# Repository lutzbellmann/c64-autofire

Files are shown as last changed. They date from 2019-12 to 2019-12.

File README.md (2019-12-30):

# c64-autofire
Autofire Adapter for the Commodore 64 Control Ports

# Features
Dual Port, configurable Autofire Adapter for the C64 with any digital Joystick

- No external power supply; powered by the Commodore 64
- Tap on/ Tap off function
- no potis, no switches, 1 button control
- configurable for 4 different autofire speeds; 10Hz, 3,8Hz, 1,9Hz, 1,2Hz
- highly stable autofire frequency, due to hardware timers
- Port A and Port B fully independent
- fire button overrides autofire (f.e. load weapon *KATAKIS*)
- port functions fully retained; mouse or other appliances can be used without restrictions
- autofire speed for each port is retained for next power-up (saved to eeprom)
- autofire off on computer power-up (no more glitches due to forgotten Autofire switch ;-) )

# Installation
Schematics can be found in the respective folder. I added the PCB layout from KiCAD as well as the GERBER data. I am not proficient at this, so the GERBER data ma not be good enough for PCB manufacturing. Please check for yourself. Maybe, somebody can help.
Parts list:
- PCB
- Attiny45
- 2x BZX85 Diodes 5,6V or higher
- 2x 15nF ceramic capacitors
- 2x female DB9 connector
- 2x male DB9 connector

Housing:
I have put some FreeCAD files and STLs in the respective folder. Use at will, or make your own.

Flashing the Attiny:
- compatible flash programmer needed (f.e. STK500, TL866, Arduino like programmes,....)
- WARNING: flashing the Attiny will only work once with ISP programmers, since the Fuses are written to disable the Reset pin (PB5).
  For future programming/ reuse a high voltage programmer is needed.
- to compile the *.asm file, install AVRA with "sudo apt install avra"
- to flash using an STK500 or similar programmer, install AVRDUDE: "sudo apt install avrdude"

There are in general two options for programming:
1) - Use the Makefile to produce your own binaries and flash
Fix your directories and programmer in the Makefile.
To flash the chip and write the fuses, connect your programmer incl. Attiny and run:
sudo make install

2) - Use the HEX binaries included
You can flash the chip without compiling the assembly to binary by using the *.hex file provided.
To use AVR Dude in the directory with the hex file:
sudo avrdude -p t45 -P (your interface) -c (your programmer) -B 1024 -U flash:w:C64_autofire.hex

Then you have to burn the fuses with:

sudo $(AVRDUDE) -p t45 -P (your interface) -c (your programmer) -B 1024 -U lfuse:w:0xe2:m -U hfuse:w:0x57:m

For "your interface" choose the interface your programmer is connected to. F.e. /dev/ttyACM0 or COM3.
See detailed instructions for using AVRDUDE under https://linux.die.net/man/1/avrdude.

WARNING: check your circuit properly! Connection errors and short circuits could destroy your C64! No warranty is given for any usage
of this Autofire adapter. Do not try it, if you are not knowing what you are doing. Usage at your own risk!

# Usage
Plug in the autofire adapter carfully into the C64 Control Ports and switch on the computer.

Configuration of autofire speed:
- hold down config button for the respective port and tap the joystick button 1-4 times depending on the autofire speed you want.
1x -> very slow ... 4x -> very fast; after 1 sec speed is saved for that port
- activate autofire for the respective port by tapping the config button once
- tap again for deactivation

HAVE FUN

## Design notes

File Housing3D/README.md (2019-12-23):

This folder contains all the files related to the housing.
These files currently are for the housing I have used for the prototype.
Can be sliced and 3D printed.

Use FreeCAD to work on the housing.

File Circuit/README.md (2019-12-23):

This folder contains the schematic of the circuit and all related files.
Use KiCAD to view and edit the schematic.

More to come:
- PCB layout
- Parts list

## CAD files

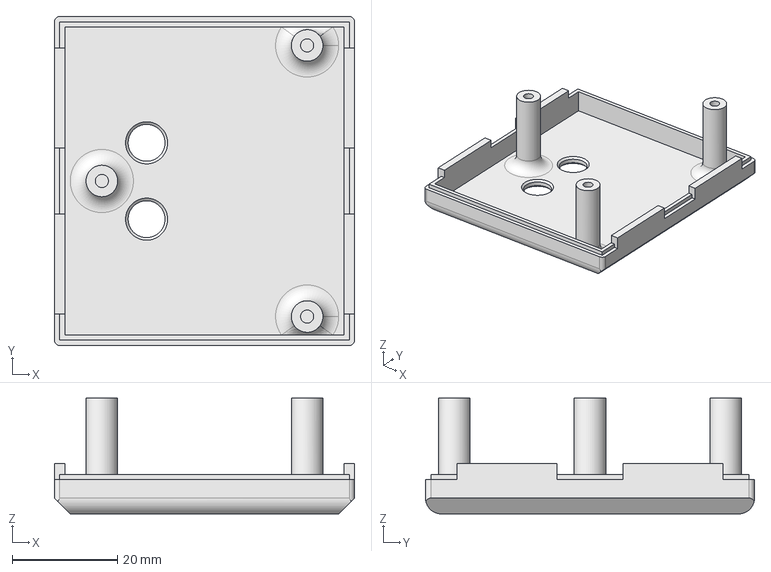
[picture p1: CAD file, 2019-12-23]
Housing3D/C64_autofire_top.FCStd
57.0 x 62.5 x 22.0 mm

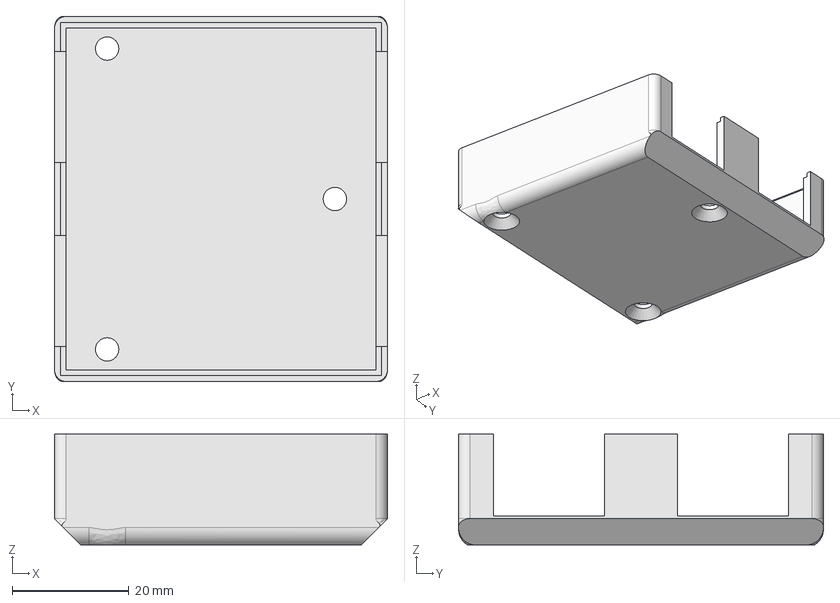
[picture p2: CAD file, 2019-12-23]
Housing3D/C64_autofire_bottom.FCStd
57.1 x 62.5 x 19.0 mm

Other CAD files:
C64_autofire.obj
Housing3D/C64_autofire_bottom.stl
Housing3D/C64_autofire_top.stl

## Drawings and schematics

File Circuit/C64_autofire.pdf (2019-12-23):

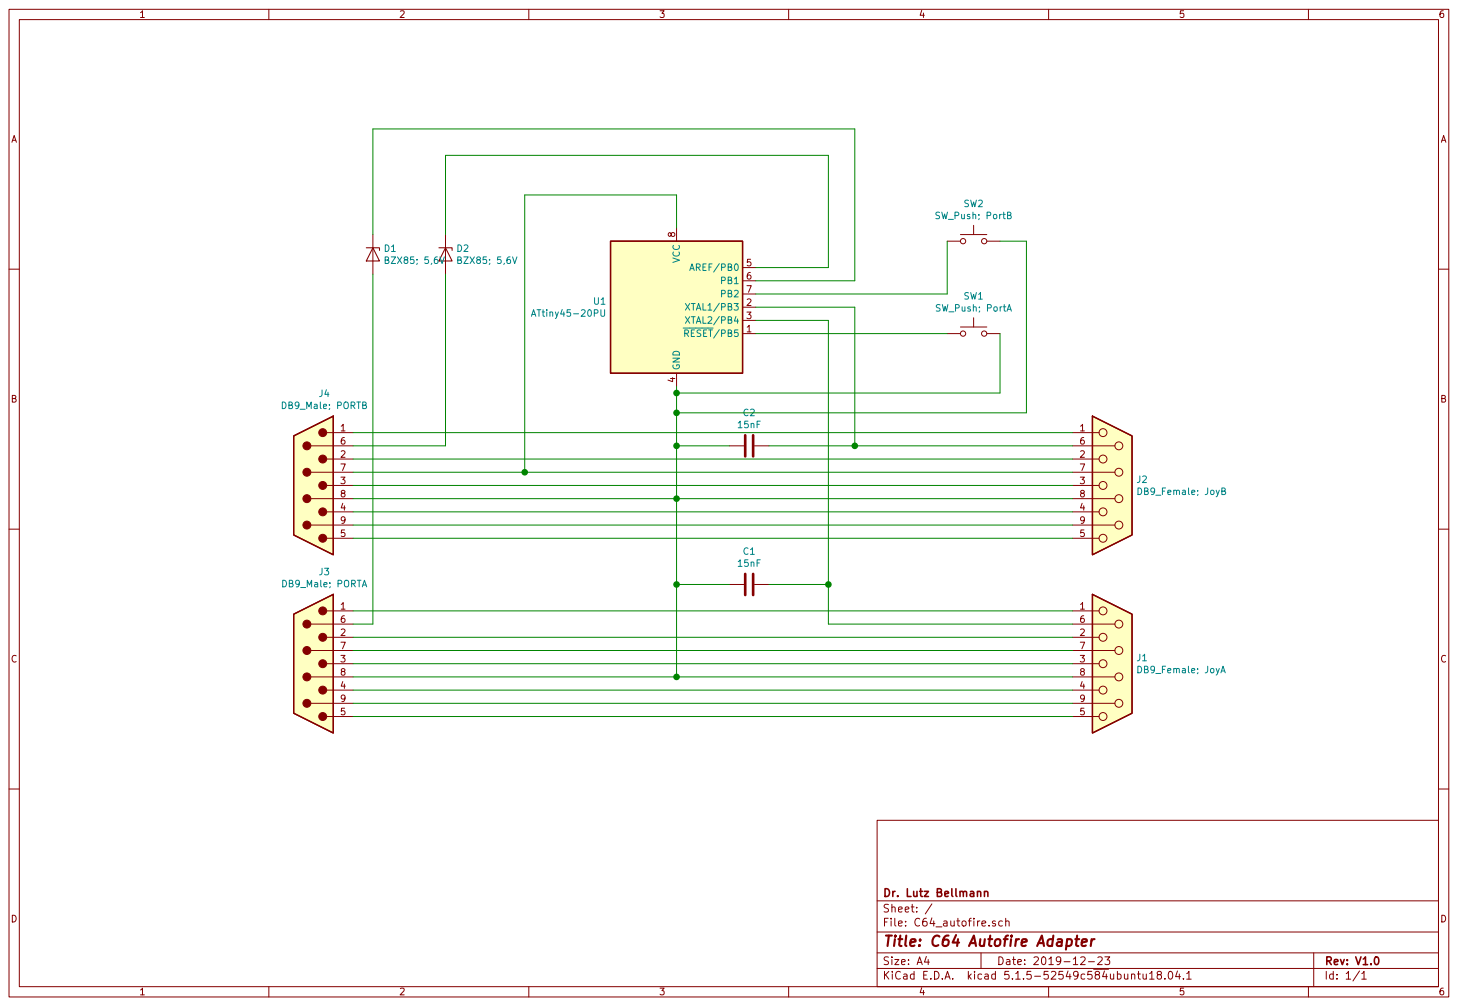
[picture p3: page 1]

File: C64_autofire.sch Sheet: / Dr. Lutz Bellmann

Id: 1/1 Title: C64 Autofire Adapter

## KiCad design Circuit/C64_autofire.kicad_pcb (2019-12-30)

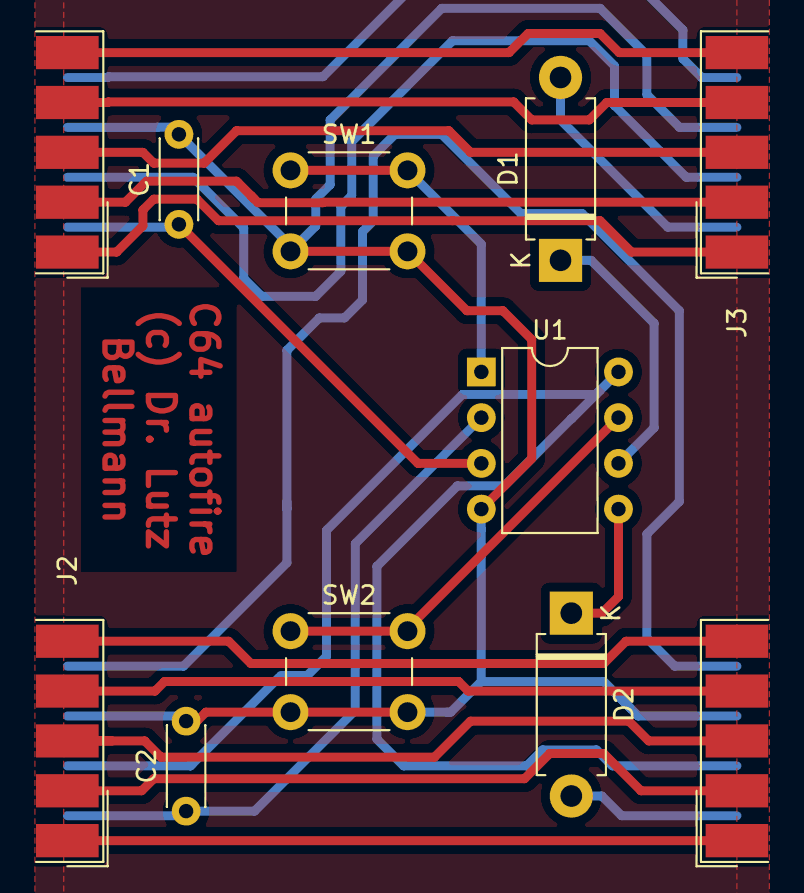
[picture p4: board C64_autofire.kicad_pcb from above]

Board: 2 copper layers, 11 parts (0 on the bottom side), 23 nets.

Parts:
C1, C2: 15nF; C_Disc_D4.3mm_W1.9mm_P5.00mm
D1, D2: BZX85; 5,6V; D_DO-15_P10.16mm_Horizontal
J1: DB9_Female; JoyA; DSUB-9_Female_EdgeMount_P2.77mm
J2: DB9_Female; JoyB; DSUB-9_Female_EdgeMount_P2.77mm
J3: DB9_Male; PORTA; DSUB-9_Male_EdgeMount_P2.77mm
J4: DB9_Male; PORTB; DSUB-9_Male_EdgeMount_P2.77mm
SW1: SW_Push; PortA; SW_PUSH_6mm_H9.5mm
SW2: SW_Push; PortB; SW_PUSH_6mm_H9.5mm
U1: ATtiny45-20PU; DIP-8_W7.62mm

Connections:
unnamed: C1.1, J1.6, U1.3
unnamed: C1.2, C2.2, J1.8, J2.8, J3.8, J4.8, SW1.2, SW2.2, U1.4
unnamed: C2.1, J2.6, U1.2
unnamed: D1.1, U1.6
unnamed: D1.2, J3.6
unnamed: D2.1, U1.5
unnamed: D2.2, J4.6
unnamed: J1.1, J3.1
unnamed: J1.2, J3.2
unnamed: J1.3, J3.3
unnamed: J1.4, J3.4
unnamed: J1.5, J3.5
unnamed: J1.7, J3.7
unnamed: J1.9, J3.9
unnamed: J2.1, J4.1
unnamed: J2.2, J4.2
unnamed: J2.3, J4.3
unnamed: J2.4, J4.4
unnamed: J2.5, J4.5
unnamed: J2.7, J4.7, U1.8
unnamed: J2.9, J4.9
unnamed: SW1.1, U1.1
unnamed: SW2.1, U1.7

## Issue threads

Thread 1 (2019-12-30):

Pre-compiled HEX

mamejay, 2019-12-30:
Hello there.  Great device.  I am wanting to make one and just wondered if the C64_autofire.hex is ready to go.
Also if this is ready to go, when I program using avrdude do I need to add any fuse settings?
I see lfuse:w:0xe2:m -U hfuse:w:0x57:m in the Makefile

Thanks

lutzbellmann, 2019-12-30:
Hi!
The HEX is ready to go. With sudo make install you will create a new one, flash AND set the fuses.
Be aware that all pins of the Attiny are used incl PB5. The fuses are set to RSTDISBL. You can‘t flash the device again with ISP afterwards, you need HV Serial programmer or new Attiny.

mamejay, 2019-12-30:
Excellent.  So I can program your HEX file using a command something like this?
**_avrdude -c arduino -P com3 -p t45 -b 19200 -U flash:w:C64_autofire.hex:i -B 1024 -U lfuse:w:0xe2:m -U hfuse:w:0x57:m_**

lutzbellmann, 2019-12-30:
this should work. Thanks for bringing this up.
Installation instructions should be updated for different programmers.

lutzbellmann, 2019-12-30:
Installation instructions will be handeled, when there is time

Closed 2019-12-30.

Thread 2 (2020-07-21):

Cannot get this to work

mamejay, 2020-07-21:
Hi There.  I have managed to build a unit up.  I have double and tripled checked your schematic and board against my board.
I programmed the attiny using a Uno and using the follow command in windows
avrdude -c arduino -P com3 -p t45 -b 19200 -U flash:w:C64_autofire.hex:i -B 1024 -U lfuse:w:0xe2:m -U hfuse:w:0x57:m

This successfully wrote no issues.
The only thing I can see I that could be wrong is that I am using BZV55 5.6V zener diode instead of the BZX85 one your mentioned.
I have checked the joystick button input on either side of the diode.  On the cathode side I am not getting any pulldown on the signal at all.
 I have checked the spec sheet but cannot determine what the main differences are.    Could this be the issue I am having?
Let me know if you have any advise.
Thanks

lutzbellmann, 2020-07-21:
Hi mamejay,
I checked the circuit myself again with my adapter and could not find any issue(schematics should be ok).
Type of Zdiode should not matter, if >=5.6V. This is only there as a precaution to avoid any current flow towards the C64 during switching of the port.
If you have programmed a successfully, you **should not** be able to program the Attiny again with a serial programmer, since the fuses disable the reset port.
So the hex must be written first, and then the fuses. With a new t45 do:
avrdude -c arduino -P com3 -p t45 -b 19200 -U flash:w:C64_autofire.hex:i -B 1024
avrdude -c arduino -P com3 -p t45 -b 19200 -B 1024 -U lfuse:w:0xe2:m -U hfuse:w:0x57:m
I am not sure what Arduino IDE is actually doing, so this could be a hint.

mamejay, 2020-07-22:
Thanks for that.  I tried programming another chip by splitting programming as you mentioned and doing the fuses after.
After flashing the hex the chip was not recognised so could not apply the fuses.
I did another using the single line for AVRdude but same issues where the button does nothing..  Here is the output from the command.
Anyway might just put this one in the too hard basket.  Thanks.

C:\Users\Jason\Google Drive\AVRDUDE>avrdude -c arduino -P com3 -p t45 -b 19200 -U flash:w:C64_autofire.hex:i -B 1024 -U lfuse:w:0xe2:m -U hfuse:w:0x57:m

avrdude: AVR device initialized and ready to accept instructions

Reading | ################################################## | 100% 0.04s

avrdude: Device signature = 0x1e9206 (probably t45)
avrdude: NOTE: "flash" memory has been specified, an erase cycle will be performed
         To disable this feature, specify the -D option.
avrdude: erasing chip
avrdude: reading input file "C64_autofire.hex"
avrdude: writing flash (580 bytes):

Writing | ################################################## | 100% 1.15s

avrdude: 580 bytes of flash written
avrdude: verifying flash memory against C64_autofire.hex:
avrdude: load data flash data from input file C64_autofire.hex:
avrdude: input file C64_autofire.hex contains 580 bytes
avrdude: reading on-chip flash data:

Reading | ################################################## | 100% 0.59s

avrdude: verifying ...
avrdude: 580 bytes of flash verified
avrdude: reading input file "0xe2"
avrdude: writing lfuse (1 bytes):

Writing | ################################################## | 100% 0.04s

avrdude: 1 bytes of lfuse written
avrdude: verifying lfuse memory against 0xe2:
avrdude: load data lfuse data from input file 0xe2:
avrdude: input file 0xe2 contains 1 bytes
avrdude: reading on-chip lfuse data:

Reading | ################################################## | 100% 0.02s

avrdude: verifying ...
avrdude: 1 bytes of lfuse verified
avrdude: reading input file "0x57"
avrdude: writing hfuse (1 bytes):

Writing | ################################################## | 100% 0.03s

avrdude: 1 bytes of hfuse written
avrdude: verifying hfuse memory against 0x57:
avrdude: load data hfuse data from input file 0x57:
avrdude: input file 0x57 contains 1 bytes
avrdude: reading on-chip hfuse data:

Reading | ################################################## | 100% 0.02s

avrdude: verifying ...
avrdude: 1 bytes of hfuse verified

avrdude: safemode: Fuses OK (E:FF, H:57, L:E2)

avrdude done.  Thank you.

lutzbellmann, 2020-07-25:
Sorry for the late reply. Don't give up yet.
Please try the following:
- Take the Attiny, where you couldn't write the fuses after writing the hex
- write the HEX again (not the fuses!), try a lower -B value in the AVRDUDE command line (Bitlock value)
- try until you can consistently write the hex on the chip (start with -B 512, -B 256 , ...)
- after that: write the fuses

Explanation:
For the autofire the clockspeed of the Attiny is adjusted to 31.25kHz. The Attiny can't keep up with the speed of the programmer, after you have written the hex with the standard Bitlock value of 1. Higher Bitlock values lower the frequency of certain programmers. 1024 worked for me, may be too much for your arduino programmer.

mamejay, 2020-07-25:
Thanks for that.  Just tried again with a fresh chip as the other one I have no idea were it went.
I get the same issue.  I can program the hex once and then chip is not recognised.   I try -B 512 -B 256 -B 128 -B 64 etc but same.
I will look at if there is limitations with the Uno.

mamejay, 2020-07-25:
Looks like Uno as a ISP is not ideal.
https://forum.arduino.cc/index.php?topic=71973.0
Looks like the -B switch does not work with a UNO.  Always handy to have another option.  I will see if I can grab one locally here in Australia which will be pretty much impossible

lutzbellmann, 2020-07-25:
oh greetings to the other side of the world from Germany! :-)
I am pretty sure you will be able to find a decent programmer. Get a TL866 II+ or compatible. The thing can do almost anything; even locks open your dead chips.

Closed 2020-07-25.

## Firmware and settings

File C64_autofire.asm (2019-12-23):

;  C64 Autofire Adapter
;  Version 1.0
;  Attiny45 compatible source code
;  (c) Dr. Lutz Bellmann

.include "tn45def.inc"

.dseg			; Data Segment
speedA: .byte 1		; Autofire Speed Channel A
speedB: .byte 1		; Autofire Speed Channel B
sp_table: .byte 4	; Speed Table

.cseg
.org	0x0000

rjmp reset		;Reset handler
reti;rjmp INT0		;IRQ0 handler
rjmp pc_int0		;Pin change handler
reti;rjmp TIMER1_COMPA	;Timer1 compare match 1A
reti;rjmp TIMER1_OVF	;Timer1 overflow handler
reti;rjmp TIMER0_OVF	;Timer0 overflow handler
reti;rjmp EE_RDY	;EEPROM Ready handler
reti;rjmp ANA_COMP	;Analog Comparator handler
reti;rjmp ADC		;ADC Conversion Handler
reti;rjmp TIMER1_COMPB	;Timer1 compare match 1B
reti;rjmp TIMER0_COMPA	;Timer0 compare match 0A
reti;rjmp TIMER0_COMPB	;Timer0 compare match 0B
reti;rjmp WDT		;WatchDog handler
reti;rjmp USI_START 	;USI Start handler
reti;rjmp USI_OVF	;USI Overflow handler

reset:
ldi r16, high(RAMEND)
out SPH, r16
ldi r16, low(RAMEND)	; Stack Allocation
out SPL, r16
clr r16			; clear registers
clr r20
clr r21
ldi XL, low(sp_table)	; X Pointer to Speed Table
ldi XH, high(sp_table)
ldi r16, 52		; save speed table to data segment
st X+, r16
ldi r16, 32		; save speed table to data segment
st X+, r16
ldi r16, 16
st X+, r16
ldi r16, 6
st X+, r16
ldi r16,0b00000011
out ddrb, r16		; all pins to input, except fire (PB0/1)
ldi r16, 0b00111111	
out portb, r16		; all inputs pull-up, except Joyport A/B
ldi r16, 0b10000000
ldi r17, 0b00001000
out CLKPR, r16		; enable clock write
out CLKPR, r17		; Clock divider 256-->31,25kHz
in r16, PCMSK
sbr r16, (1<<PCINT2)|(1<<PCINT5)
out PCMSK, r16		; Mask PB2 and PB5 as Interrupt PCINT
in r16, GIMSK
sbr r16, (1<<PCIE)
out GIMSK, r16		; PCINT Interrupt enable
rcall eeprom_read	; read speed data
sei			; enable global interrupts

main:
sbrs r20, PB0		; ON command for Autofire A?
rcall deconfigure_T0	; if not, deconfigure Autofire A
sbrc r20, PB0
rcall configure_T0	; if yes, configure Autofire A
sbrs r20, PB1		; ON command for Autofire B?
rcall deconfigure_T1	; if not, deconfigure Autofire B
sbrc r20, PB1
rcall configure_T1	; if yes, configure Autofire B
sbis pinb, PB4		; Joystick A Fire pressed?
rcall fireA		; if yes, jump to Fire A Override
sbic pinb, PB4		; Joystick A Fire pressed?
rcall fireAn		; if not, jump to Fire An
sbis pinb, PB3		; Joystick B Fire pressed?
rcall fireB		; if yes, jump to Fire B Override
sbic pinb, PB3		; Joystick B Fire pressed?
rcall fireBn		; if not , jump to Fire Bn
rcall chkconf		; check configuration
rjmp main		; loop back

chkconf:
cli			; turn interrupts off
eor r20, r21		; toggle activation bits in r20 if set in r21
clr r21			; clear toggle commands
sei			; turn interrupts on
ret
 
configure_T0:
sbis pinb, PB4		; fire currently being pressed?
ret			; if yes, do not activate
in r16, TCCR0A
sbrc r16, COM0A0	; is autofire active?
ret			; if yes, do not activate again
sbi portb, PB0		; FireA off
clr r16
out TCNT0, r16		; set Timer 0 -> 0
ldi r16, 0b01000010
out TCCR0A, r16		; Timer0, CTC, OC0A toggle
ldi r16, 0b00000100
out TCCR0B, r16		; Timer0, Prescaler=256
lds r16, speedA		; get configured speed
out OCR0A, r16
ret

deconfigure_T0:
in r16, TCCR0A
sbrs r16, COM0A0	; is autofire active?
ret			; if not, do not deactivate again
clr r16
out TCCR0A, r16		; clear Timer configuration
sbi portb, PB0		; Fire A line to high (unpressed)
ret

configure_T1:
sbis pinb, PB3		; fire currently being pressed?
ret			; if yes, do not activate
in r16, TCCR1
sbrc r16, COM1A0	; is autofire active?
ret			; if yes, do not activate again
sbi portb, PB1		; FireA off
clr r16
out TCNT1, r16		; set Timer1 -> 0
ldi r16, 0b10011001
out TCCR1, r16		; Timer1, CTC1, OC1A toggle, Prescaler 256
lds r16, speedB		; get speed from SRAM		
out OCR1A, r16		; set autofire frequency
out OCR1C, r16		
ret

deconfigure_T1:
in r16, TCCR1
sbrs r16, COM1A0	; is autofire active?
ret			; if not, do not deactivate again
clr r16
out TCCR1, r16		; clear Timer configuration
sbi portb, PB1		; Fire B line to high (unpressed)
ret

fireA:
rcall deconfigure_T0	; switch off autofire
cbi PORTB, PB0		; pull JoyA Input to GND
sbrc r20, PB0		; are we in autofire mode?
sbr r20, (1<<PB3)	; if yes, indicate reenable auto fire
sbis pinb, pb2		; config button held down?
rcall select_A		; if yes, switch to config mode
ret

fireAn:
sbi portb, PB0		; Fire A line high
sbrc r20, PB3		; was autofire enabled, when fire was pressed?
rcall configure_T0	; if yes, enable autofire
cbr r20, (1<<PB3)	; autofire history bit
ret

fireB:
rcall deconfigure_T1	; switch off autofire
cbi PORTB, PB1		; pull JoyB Input to GND
sbrc r20, PB1		; are we in autofire mode?
sbr r20, (1<<PB4)	; if yes, indicate reenable auto fire
sbis pinb, pb5		; config button held down?
rcall select_B		; if yes, switch to config mode
ret

fireBn:
sbi portb, PB1		; Fire B line high
sbrc r20, PB4		; was autofire enabled, when fire was pressed?
rcall configure_T1	; if yes, enable autofire
cbr r20, (1<<PB4)	; autofire history bit
ret

select_A:
cli			; disable interrupts
ldi r17, 4
ldi XL, low(sp_table)	; X Pointer to Speed Table
ldi XH, high(sp_table)
sbi portb, pb0		; Joy A high
loop1:
rcall entprellen	; debounce joybutton
ld r16, X+		; get speed
sts speedA, r16		; store speed
dec r17			; dec counter
brne loop2		; counter 0?
ldi r17, 4		; counter to 3 again
ldi XL, low(sp_table)	; X Pointer to Speed Table
ldi XH, high(sp_table)
loop2:
sbis pinb, PB4		; Joystick Button still pressed?
rjmp loop2		; if yes, wait
rcall entprellen	; debounce joybutton
rcall onesec		; set 1sec timer
loop3:
sbis pinb, PB4		; Joystick pressed again?
rjmp loop1		; set next speed in table
in r16, TCNT0		; one second waiting time over?
cpi r16, 0
brne loop3		; if not chekc button again
clr r16
out TCCR0A, r16		; clear timer configuration
out TCCR0B, r16
cbr r20, (1<<PB0)|(1<<PB3); do not start Autofire 
cbr r21, (1<<PB0)	; after configuration
rcall eeprom_write	; save new speed to eeprom
sei			; enable interrupts
ret			; setup complete

select_B:
cli			; disable interrupts
ldi r17, 4
ldi XL, low(sp_table)	; X Pointer to Speed Table
ldi XH, high(sp_table)
sbi portb, pb1		; Joy B high
loop6:
rcall entprellenB	; debounce joybutton
ld r16, X+		; get speed
sts speedB, r16		; store speed
dec r17			; dec counter
brne loop7		; counter 0?
ldi r17, 4		; counter to 4 again
ldi XL, low(sp_table)	; X Pointer to Speed Table
ldi XH, high(sp_table)
loop7:
sbis pinb, PB3		; Joystick Button still pressed?
rjmp loop7		; if yes, wait
rcall entprellenB	; debounce joybutton
rcall onesecB		; set 1sec timer
loop8:
sbis pinb, PB3		; Joystick pressed again?
rjmp loop6		; set next speed in table
in r16, TCNT1		; one second waiting time over?
cpi r16, 0
brne loop8		; if not chekc button again
clr r16
out TCCR1, r16		; clear timer configuration
cbr r20, (1<<PB1)|(1<<PB4); do not start Autofire 
cbr r21, (1<<PB1)	; after configuration
rcall eeprom_write	; save new speed to eeprom
sei			; enable interrupts
ret
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

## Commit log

2019-12-23 FreeCAD and STL files for Autofire Adapter
    [C64_autofire_bottom.FCStd, C64_autofire_bottom.stl, C64_autofire_top.FCStd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]
2019-12-23 Schematic of Autofire Adapter
    [C64_autofire.sch]
2019-12-30 GERBER Data and PCB layout added
    Warning! data has not been confirmed working. Experimental!
    [C64_autofire-B_Cu.gbr, C64_autofire-B_Mask.gbr, C64_autofire-B_Paste.gbr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]
2019-12-30 updated instructions: installation; use of GERBER data
